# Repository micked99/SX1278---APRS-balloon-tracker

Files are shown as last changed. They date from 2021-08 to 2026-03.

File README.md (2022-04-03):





2021-10-09 PCB_SX1278_Micro


# SX1278
Aprs using Lora sx1278

Clone of this project, using a SX1278 Lora module or just the IC SX1278 as aprs tx, ALL credit goes to https://github.com/DO4AS/jufo-project-radiosonde
I have only made the pcb:s and edited the fw in a small way that fits my needs.

PCB for both LORA sx1278 module and barebone 1278 ic, make sure you get the correct module, at least 4 Lora models avalible with different pinout.

The sketch on the 328 works at 8Mhz or 16Mhz, Im using 8Mhz to save 5mA compared to 16Mhz

Fuses for 328: FD D9 FE

1278-Micro_2021-10-09.zip is the CAM files for pcb production/order

Latest PCB have the option for tcxo drive of the 1278, but the standard 32Mhz xo footprint can stil be used, gps antenna moved to the "top" + some small tweaks and fixes.

Adjust the "const float baud_adj = 0.952;" setting for 3 or 4 "strokes" in Direwolf, see info here https://forums.qrz.com/index.php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   
I have the best decode rate with 0.950 - 0.964 depending on xo/tcxo used, so you need to tweek this for every board.

Also test the transmitted audio against this program - AFSK1200, if it decodes the audio it should maximize the chanses of your signal to be decoded while in flight
https://sourceforge.net/projects/qtmm/

DG4NOB version incorporates more telemetry readings like Temp from internal 328 sensor, Voltage, Vertical speed in m/s etc

TBTracker and horusbinary_tracker use the same pcb layout and is 100% compatible with the above, those fw transmitt, 4FSK, RTTY and Lora, original authors git at  https://github.com/RoelKroes  with small adjustment to fit "my" pcb layout

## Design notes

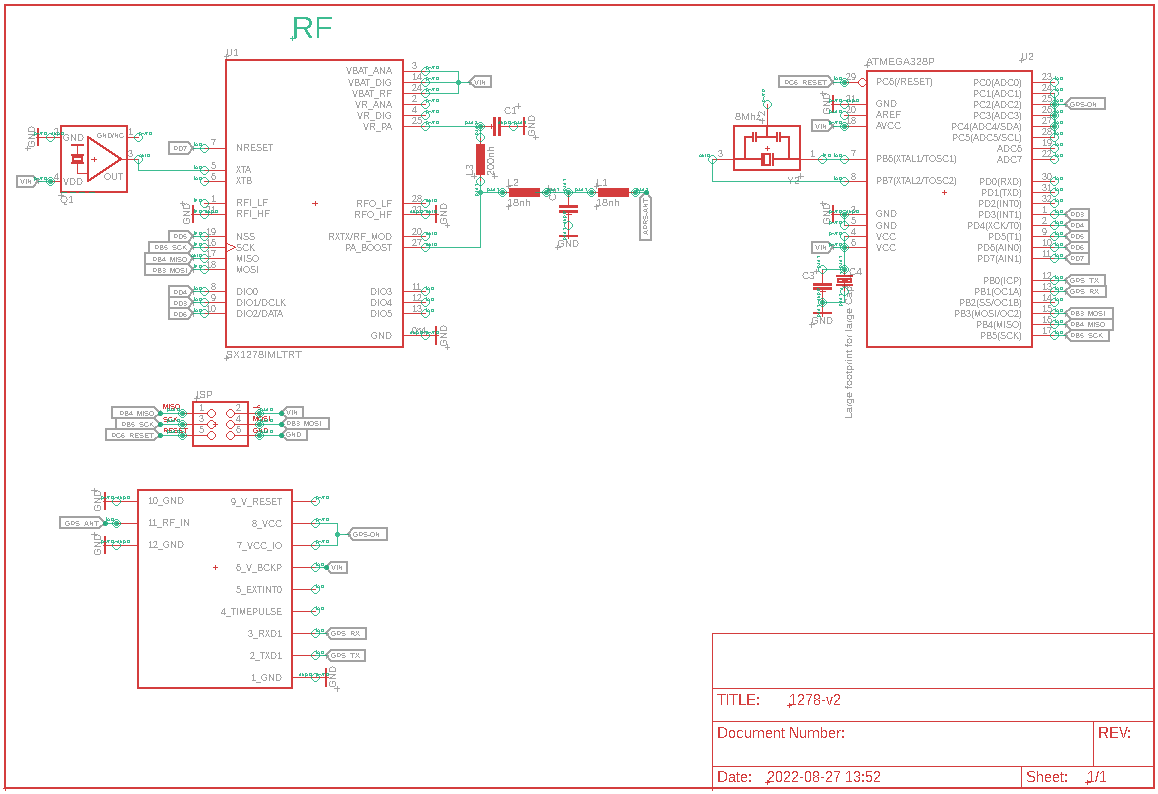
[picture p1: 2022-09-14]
2022-09-05 07_23_53-2 Schematic - C__Users_i5_Dropbox_!hab_SX1278_1278-v2.sch.png

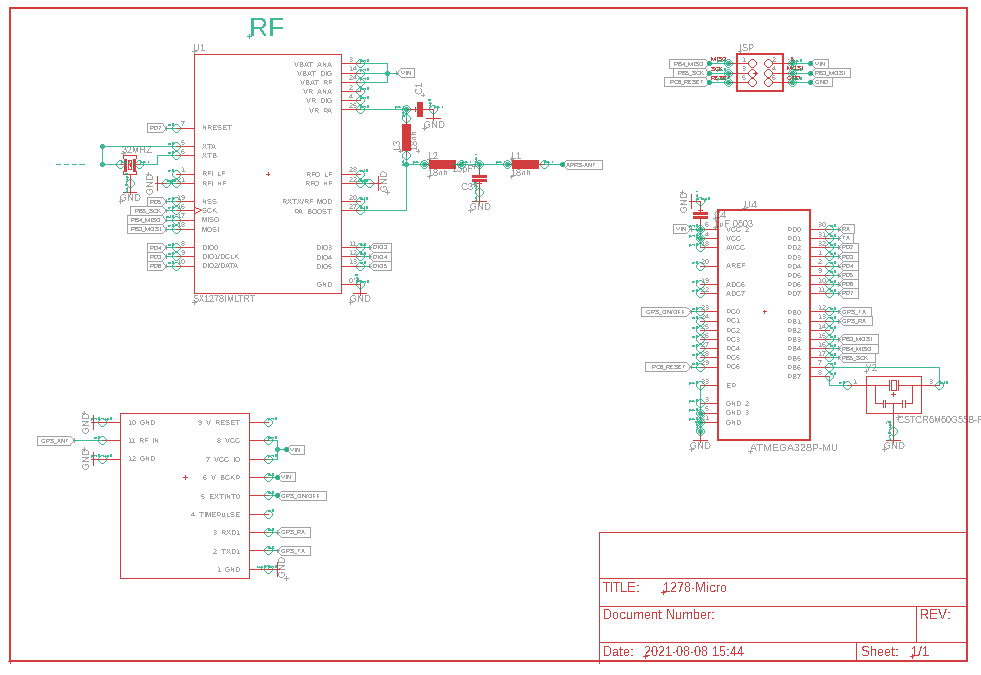
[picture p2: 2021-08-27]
2021-08-27 20_43_28-1 Schematic - C__Users_i5_Dropbox_!hab_SX1278_1278-Micro.sch.png

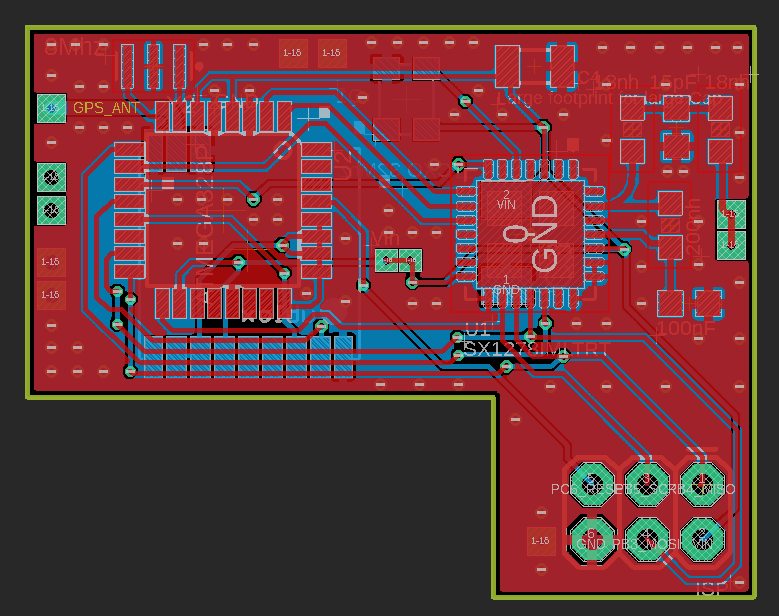
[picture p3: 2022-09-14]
2022-09-05 07_23_25-1 Board - C__Users_i5_Dropbox_!hab_SX1278_1278-v2.brd.png

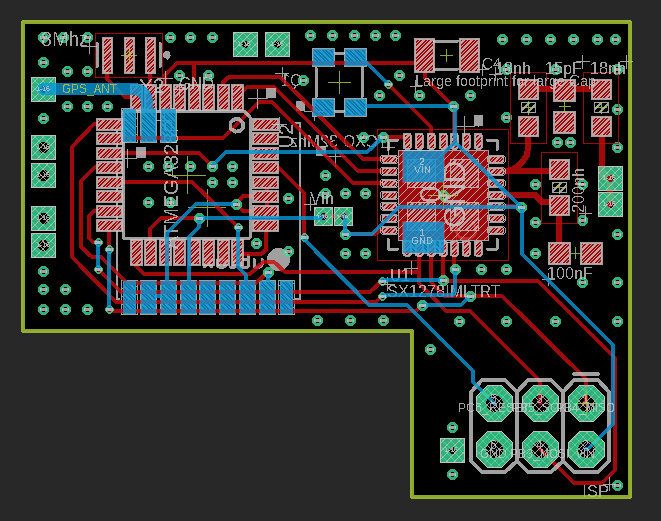
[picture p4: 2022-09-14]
2022-09-14 08_24_28-1 Board - C__Users_i5_Dropbox_!hab_SX1278_1278-v2.brd.png

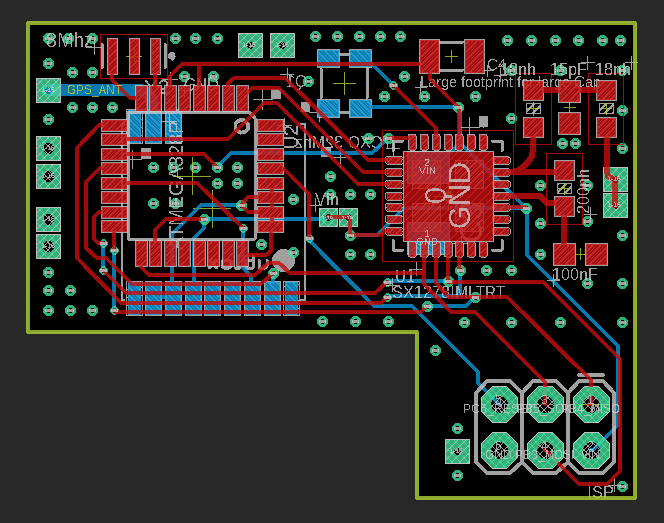
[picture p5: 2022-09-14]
2022-09-05 07_22_48-1 Board - C__Users_i5_Dropbox_!hab_SX1278_1278-v2.brd.png

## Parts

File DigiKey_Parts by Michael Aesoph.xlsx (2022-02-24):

Index | Quantity | Part Number | Manufacturer Part Number | Description | Customer Reference | Available | Backorder | Unit Price | Extended Price USD
1 | 10 | 399-17366-1-ND | C0402C150C5GAC7867 | CAP CER 15PF 50V NP0 0402 | C2 | 10 | 0 | 0.679 | 6.79
2 | 12 | 334-1063-1-ND | HFI-201209-18NJ | FIXED IND 18NH 300MA 450MOHM SMD | L1, L2 | 12 | 0 | 0.098 | 1.18
3 | 6 | A103762CT-ND | 36502AR20JTDG | FIXED IND 200NH 400MA 660MOHM SM | L3 | 6 | 0 | 0.5 | 3.00
4 | 6 | 1908-1044-1-ND | O 32,0-JT32C-A-K-3,3-LF | XTAL OSC TCXO 32.0000MHZ HCMOS | Q1 | 6 | 0 | 2.96 | 17.76
5 | 7 | 535-10302-1-ND | ABM8G-32.000MHZ-B4Y-T | CRYSTAL 32.0000MHZ 10PF SMD | 32MHz | 7 | 0 | 0.82 | 5.74
6 | 7 | 478-8364-1-ND | F950G227KAAAQ2 | CAP TANT 220UF 10% 4V 1206 | C3 | 7 | 0 | 1.11 | 7.77
7 | 7 | 50-ECS-CTE-8.00-10-CT-ND | ECS-CTE-8.00-10-TR | CERAMIC RES 8.00MHZ 10PF SMD | Y1 | 7 | 0 | 0.36 | 2.52

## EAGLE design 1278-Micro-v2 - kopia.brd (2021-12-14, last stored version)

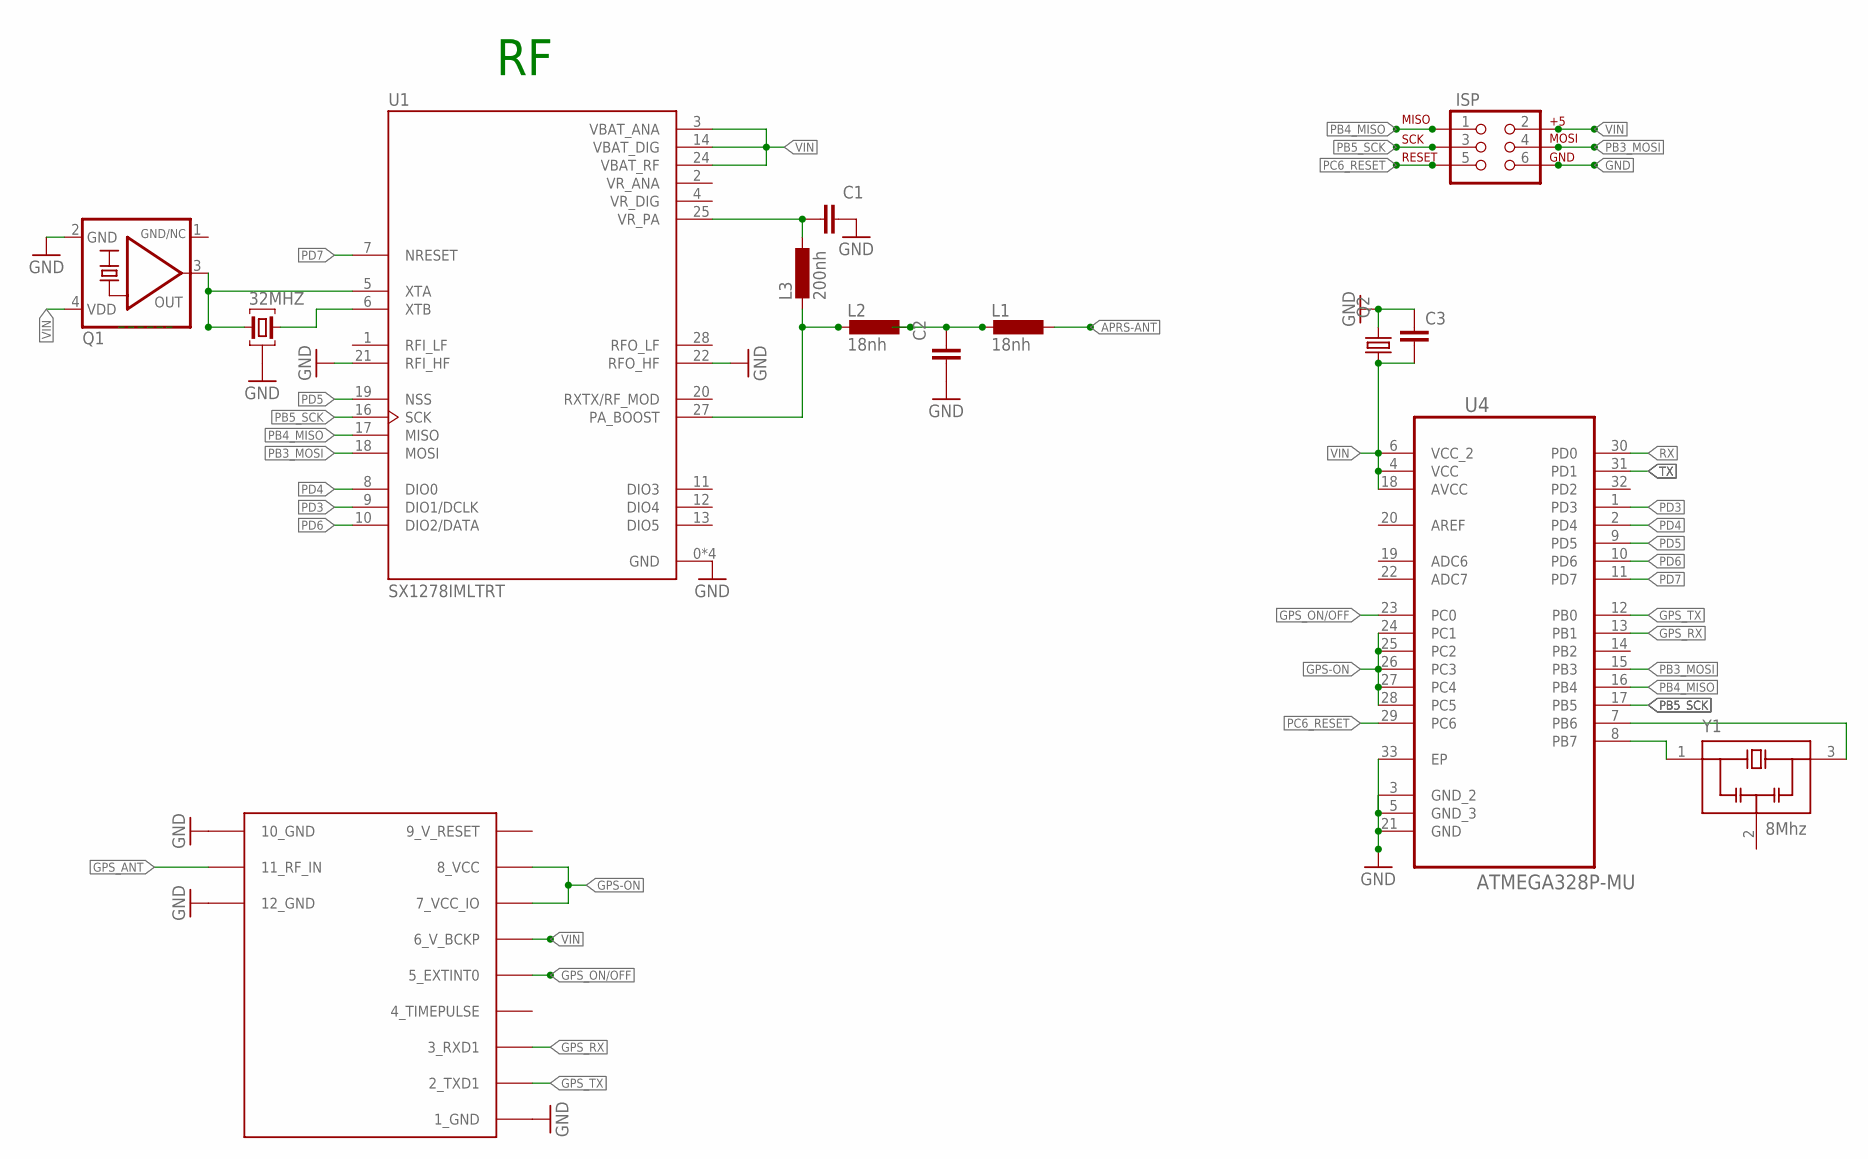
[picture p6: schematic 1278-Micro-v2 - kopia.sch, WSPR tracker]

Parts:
32MHZ: 16Mhz; ABM8G
C1: 100nF; C0603K
C2: 15pF; C0603K
C3: C-EUC1808; C1808
ISP: AVR_SPI_PRG_6PTH; 2X3
L1, L2: 18nh; L2012C
L3: 200nh; L2012C
Q1: TCXO 32Mhz; 3.2X2.5_KXO-84-TCXO
Q2: KX-327-NHF; 3.2X1.5
U1: SX1278IMLTRT; QFN65P600X600X100-29N
U4: ATMEGA328P-MU; QFN50P500X500X100-33N
U$2: UBLOX_MAX
Y1: 8Mhz; OSC_CSTCE12M0G15L08-R0

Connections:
9_V_RESET: U$2.9_V_RESET
AAA: 32MHZ.1, Q1.3 (OUT), U1.5 (XTA)
APRS-ANT: L1.1
GND: 32MHZ.2, 32MHZ.4 (2), C1.2, C2.1, C3.1, ISP.6, Q1.2 (GND), Q2.2, U1.0 (GND), U1.15 (GND), U1.21 (RFI_HF), U1.22 (RFO_HF), U1.23 (GND), U1.26 (GND), U4.3 (GND_2), U4.5 (GND_3), U4.21 (GND), U4.33 (EP), U$2.1_GND, U$2.10_GND, U$2.12_GND, Y1.2 (GND)
GND/NC: Q1.1 (GND/NC)
GPS-ON: U4.24 (PC1), U4.25 (PC2), U4.26 (PC3), U4.27 (PC4), U4.28 (PC5), U$2.7_VCC_IO, U$2.8_VCC
GPS_ANT: U$2.11_RF_IN
GPS_ON/OFF: U4.23 (PC0), U$2.5_EXTINT0
GPS_RX: U4.13 (PB1), U$2.3_RXD1
GPS_TX: U4.12 (PB0), U$2.2_TXD1
unnamed: U4.7 (PB6), Y1.3 (OUT)
unnamed: U4.8 (PB7), Y1.1 (IN)
unnamed: C2.2, L1.2, L2.1
unnamed: C1.1, L3.1, U1.25 (VR_PA)
unnamed: L2.2, L3.2, U1.27 (PA_BOOST)
unnamed: 32MHZ.3, U1.6 (XTB)
PB3_MOSI: ISP.4, U1.18 (MOSI), U4.15 (PB3)
PB4_MISO: ISP.1, U1.17 (MISO), U4.16 (PB4)
PB5_SCK: ISP.3, U1.16 (SCK), U4.17 (PB5)
PC6_RESET: ISP.5, U4.29 (PC6)
PD3: U1.9 (DIO1/DCLK), U4.1 (PD3)
PD4: U1.8 (DIO0), U4.2 (PD4)
PD5: U1.19 (NSS), U4.9 (PD5)
PD6: U1.10 (DIO2/DATA), U4.10 (PD6)
PD7: U1.7 (NRESET), U4.11 (PD7)
RX: U4.30 (PD0)
TX: U4.31 (PD1)
VIN: C3.2, ISP.2, Q1.4 (VDD), Q2.1, U1.3 (VBAT_ANA), U1.14 (VBAT_DIG), U1.24 (VBAT_RF), U4.4 (VCC), U4.6 (VCC_2), U4.18 (AVCC), U$2.6_V_BCKP
VR_ANA: U1.2 (VR_ANA)
VR_DIG: U1.4 (VR_DIG)

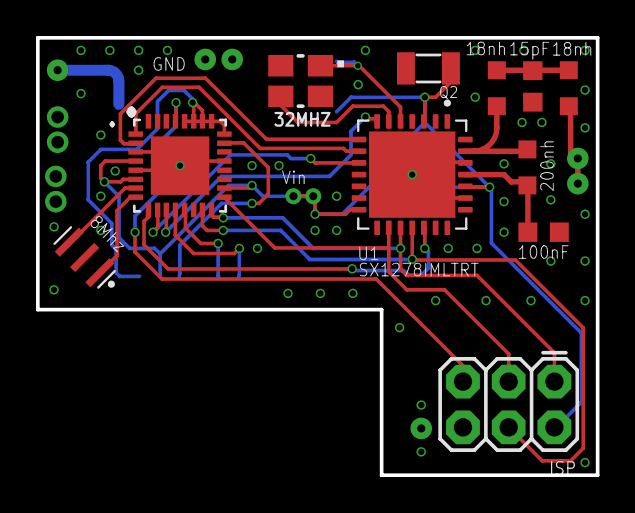
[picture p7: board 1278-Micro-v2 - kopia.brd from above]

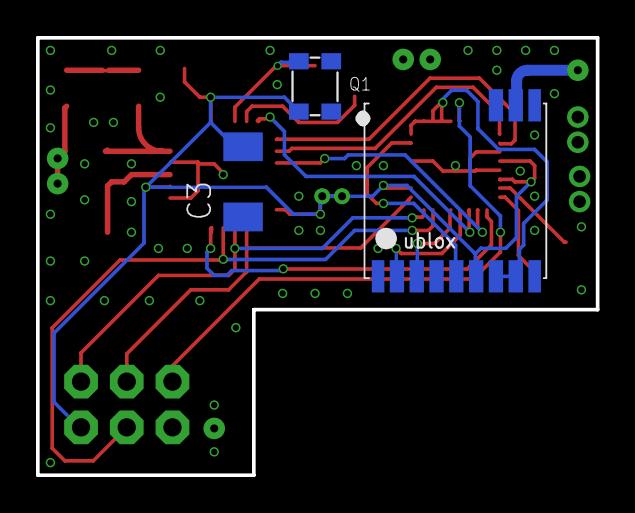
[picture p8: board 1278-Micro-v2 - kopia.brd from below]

Board: 2 copper layers, 31.1 x 24.3 mm, 14 parts (3 on the bottom side), 22 nets.

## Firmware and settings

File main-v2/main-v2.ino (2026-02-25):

//---BSS---
#include "config.h"
#include "aprs.h"
#include "gps.h"
#include "geofence.h"
#include <avr/power.h>
#include <AltSoftSerial.h>

AltSoftSerial mySerial;
aprs aprs_module;
gps gps_module;
geofence geofence_module;
float gps_latitude;
float gps_longitude;
float gps_altitude;
int gps_satellites;
int gps_speed;
String gps_latitude_DMH;
String gps_longitude_DMH;
int mcu_input_voltage;
int solar_input_voltage;
float ref_millis = float(aprs_packet_delay) * -1000;
int aprs_packet_counter = 1;

void setup()
{
  pinMode(A1, OUTPUT); //GPS on
  pinMode(A2, OUTPUT);
  pinMode(A3, OUTPUT);
  pinMode(A4, OUTPUT);
  pinMode(A5, OUTPUT);
  digitalWrite(A1, HIGH);
  digitalWrite(A2, HIGH);
  digitalWrite(A3, HIGH);
  digitalWrite(A4, HIGH);
  digitalWrite(A5, HIGH);

  //clock_prescale_set(clock_div_2);

  // pinMode(7, OUTPUT); digitalWrite(7, LOW);delay (10);digitalWrite(7, HIGH); // resets sx1278
  // pinMode(A0, OUTPUT); digitalWrite(A0, HIGH);  // Make sure the GPS is on

   mySerial.begin(9600);
   delay(1200); mySerial.println("$PCAS04,1*18\r\n");    // Sets ATGM336 to GPS only
   mySerial.end;

  // turn serial debug on or off
  #ifdef enable_serial_debug
    Serial.begin(serial_baud_rate);
    #define DEBUG_PRINT(x)  Serial.print (x)
    #define DEBUG_PRINTLN(x)  Serial.println (x)
  #else
    #define DEBUG_PRINT(x)
    #define DEBUG_PRINTLN(x)
  #endif
  
  aprs_module.begin();  // begin sx1278 spi connection
  gps_module.m_pgps_serial->begin(gps_baud_rate);  // set serial baud of gps module
 }

void loop()
{
  while (gps_module.m_pgps_serial->available())
  {
    // read gnss position data
    if (gps_module.m_pgps_device->encode(gps_module.m_pgps_serial->read())) 
    {
      // valid gnss position-fix
      if (gps_module.m_pgps_device->location.isValid())
      {
       // DEBUG_PRINTLN(millis() - ref_millis);
        
        // no packet data rate limitation - send aprs paket
        if((millis() - ref_millis) > float(aprs_packet_delay) * 1000) 
        {
          send_aprs_packet();
          ref_millis = millis();
        }     
      }
        // no packet data rate limitation
     else 
      {
      //  DEBUG_PRINTLN("INVALID");
        
        // send aprs packet after gps timeout
        if(millis() >= float(gps_timeout) * 1000)
        {
         // DEBUG_PRINTLN(millis() - ref_millis);
        
          if((millis() - ref_millis) > float(aprs_packet_delay) * 1000)
          {
            send_aprs_packet();
           
            ref_millis = millis();
          }  
        }
      }
    }
  }
}

void send_aprs_packet()
{

  // get gps location,altitude and satellite data
  gps_latitude = gps_module.m_pgps_device->location.lat();
  gps_longitude = gps_module.m_pgps_device->location.lng();
  gps_altitude = gps_module.m_pgps_device->altitude.meters();
  gps_satellites = gps_module.m_pgps_device->satellites.value();
  gps_speed = int (gps_module.m_pgps_device->speed.kmph());
  //gps_course = int (gps_module.m_pgps_device->course.deg());  
  
  gps_module.m_pgps_serial->end();   // needed for aprs to properly work

  // get aprs frequency using geofence
  float freq = geofence_module.get_aprs_frequency(gps_latitude, gps_longitude);
  
  // convert gps coordinates to DMH format needed for aprs
  gps_module.convert_gps_coordinates_to_DMH(gps_latitude, gps_longitude, &gps_latitude_DMH, &gps_longitude_DMH);
  
  // print out gps data
  //DEBUG_PRINTLN(gps_latitude);
  //DEBUG_PRINTLN(gps_longitude);
  //DEBUG_PRINTLN(gps_altitude);
  //DEBUG_PRINTLN(gps_satellites);

  // create aprs comment with payload data
  String aprs_comment = aprs_module.create_comment(gps_altitude, aprs_packet_counter, gps_speed, gps_satellites, additional_aprs_comment); 
  
  aprs_module.send(gps_latitude_DMH, gps_longitude_DMH, aprs_comment, freq);

  // increase aprs packet counter by one
  aprs_packet_counter = aprs_packet_counter + 1;
  
  gps_module.m_pgps_serial->begin(gps_baud_rate);   // needed for aprs to properly work
}

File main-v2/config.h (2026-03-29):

#ifndef CONFIG_H_
#define CONFIG_H_


/*
 * aprs config
 */

 
 
  #define aprs_source_callsign "SA8BSS"
  #define aprs_source_ssid 11
  
  #define aprs_destination_callsign "APMON"
  #define aprs_digipeater "WIDE0"
  #define aprs_digipeater2 "WIDE2"
  #define aprs_digipeater_ssid 0
  #define aprs_symbol_overlay '/'
  #define aprs_symbol 'O'
  
  #define aprs_packet_delay 120      // aprs packet delay in seconds
 
  #define aprs_frequency_default     144.800  // aprs frequency default in MHz
  #define aprs_frequency_region1     144.800  // aprs frequency region1 in MHz
  #define aprs_frequency_region2     144.390  // aprs frequency region2 in MHz
  #define aprs_frequency_china       144.640  // aprs frequency china in MHz
  #define aprs_frequency_japan       144.660  // aprs frequency japan in MHz
  #define aprs_frequency_thailand    145.525  // aprs frequency thailand in MHz
  #define aprs_frequency_newzealand  144.575  // aprs frequency newzealand in MHz
  #define aprs_frequency_australia   145.175  // aprs frequency australia in MHz
 // #define aprs_frequency_uk          433.500  // aprs frequency uk ism band in MHz
  #define aprs_frequency_brazil      145.570  // aprs frequency brazil in MHz
 
  #define additional_aprs_comment "" // Additional comment


/*
 * radio  config
 */
  #define sx1278_frequency_correction 0 // frequency offset in Hz // 10ppm xo 300hz low, cold will make the freq climb
  //#define sx1278_frequency_correction -82650 // frequency offset in Hz // 144.770Mhz
  //#define sx1278_frequency_correction -52650 // frequency offset in Hz // 10ppm xo
  #define sx1278_deviation 0x32  // 48-20Khz // default 32-15Khz  // 16-10Khz // 
  #define sx1278_radio_pwm_pin 6
/*
 * gps  config
 */
  #define gps_baud_rate 9600 
  #define gps_timeout 1      // gps timeout in sec
  /*
 * serial  config
 */
  // #define enable_serial_debug
  #define serial_baud_rate 9600
  #endif /* CONFIG_H_ */

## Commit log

2021-12-14 Add files via upload
    The difference between original version and V2 is that this version turns off the GPS module completely and saves another 6-8mA, other then that its the same fw
    [1278-Micro-v2 - kopia.brd, 1278-Micro-v2 - kopia.sch]
2022-02-24 Rename 1278-Micro-v2 - kopia.brd to 1278-Micro-v2.brd
    [1278-Micro-v2.brd]
2025-09-26 Add files via upload
    Drop those libaries in the Arduino Library folder

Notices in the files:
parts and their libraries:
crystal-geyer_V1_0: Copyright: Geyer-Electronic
